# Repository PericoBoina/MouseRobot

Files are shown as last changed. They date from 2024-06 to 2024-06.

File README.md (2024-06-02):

# Robot-Laberinto

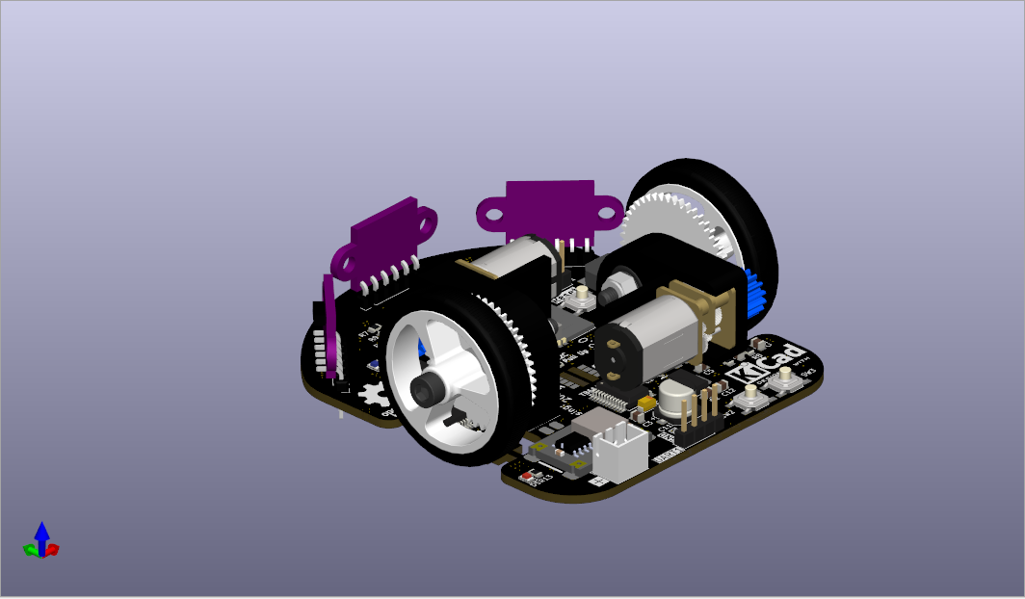
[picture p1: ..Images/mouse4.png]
Mouse3
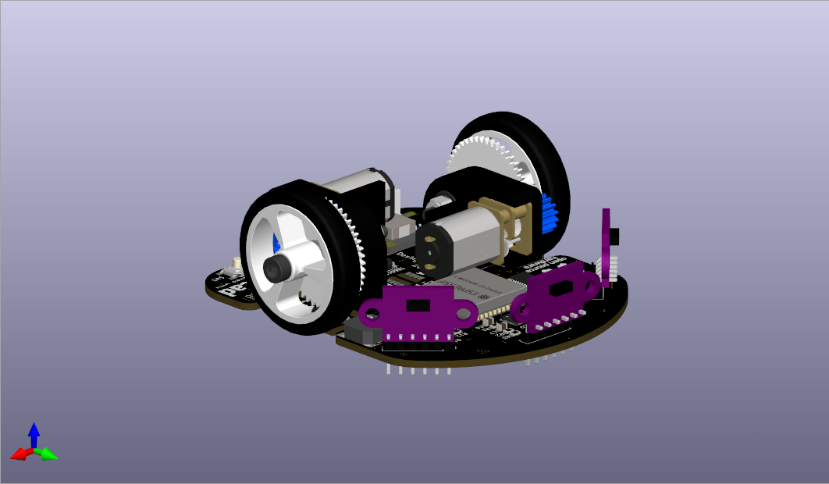
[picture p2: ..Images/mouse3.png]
Mouse4


## 👽 Hardware 👽

| | | 
|---|---  |
| Motors | N20 800RPM 6V |
| MCU | ESP32 Wroom 32U |
| Giroscope  | MPU6050 |
| Encoders | AS5145B |
| Sensors | VL53L0X |
| Wheel Gear | 48T 0.5MM(module)  |
| Motor Gear | 15T 0.5MM(module)  |

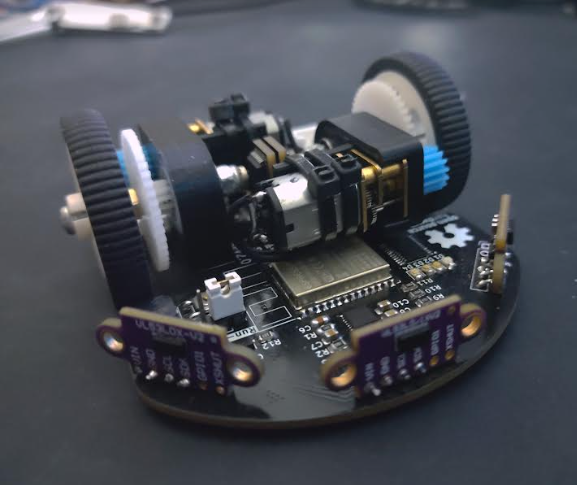
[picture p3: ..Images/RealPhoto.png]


---

Desing: Perico_197⚡

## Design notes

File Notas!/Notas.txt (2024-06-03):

Programacion:
---- Odometria:
        ***PROBLEMA RESETEO CONSTANTE AL INCLUIR LA LIBRERIA*** ☠️

---- Motion:
        *Funcion para giros -> meter funcion otro codigo nose donde esta ☠️
        *Motion -> Straight:
                * Funcion para avanzar completamente recto mediante gyro -> 🙈🙈
                * Avanzar distancia (mm) deseada -> 🙈😵‍💫

---- Sensor library:
         * algoritmo lectura paredes  -> 👍👍
         * mpu6050 hacer que aranque a 0 ->  😵‍💫
         * meter valor gyro z + inicio + ofset en libreria sensors -> 👍👍
        
---- Importante sino no se puede avanzar!!
        *averiguar que valor dan los getCount de los encoder en 1 milimetro --> 😡

-- Robot (Hardware): 
         ---- encoder ----> 👍👍      ---- buttons   ----> 👍👍     ----  leds   ----> 👍👍   
         ---- vl53l0x ----> 👍👍      ---- tb6612fng ----> 👍👍    
         ---- MPU6050 ----> 👍👍      ---- tca9548   ----> 👍👍

Emojis programing level:

         ---- 😁😁😁😁😁 ----  -> easy
         ---- 🙈🙈🙈🙈🙈 ----  -> normal
         ---- 😵‍💫😵‍💫😵‍💫😵‍💫😵‍💫 ----  -> difficult
         ---- 😡😡😡😡😡 ----  -> xtreme difficult      
         ---- ☠️☠️☠️☠️☠️ ----  -> kill me

Comandos GIT:
git init 
git commit -am "First commit"

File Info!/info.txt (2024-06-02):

Enlaces :
- https://en.wikipedia.org/wiki/Differential_wheeled_robot // Documentacion

- https://drive.google.com/file/d/1HS-5pF-UFEItbylbGvAekCrKYQvqzdeI/view //Ejemplo Arduino Odometria

- https://github.com/alfa934/wheel-odometry-arduino/blob/main/krtmi_odometry.ino // Ejemplo ArDuino Odometria
  
- http://micromouseusa.com/?page_id=1342

- https://github.com/idt12312/MIZUHO.git --> repo japo! 😁😁//

https://youtube.com/shorts/J72pE9Ghk50?si=G8V3c-wjg9_S6Kjb

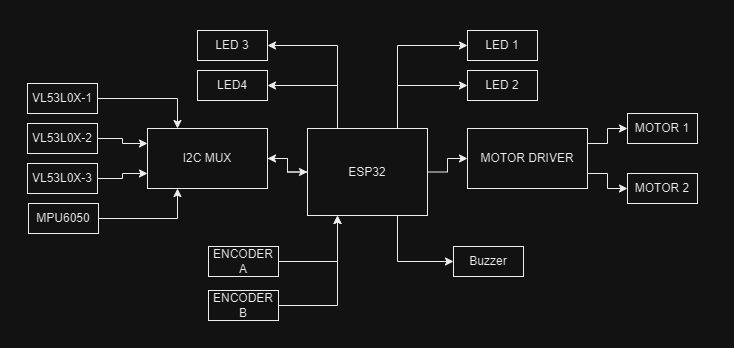
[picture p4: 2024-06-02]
..Schematic/schematic_1.png

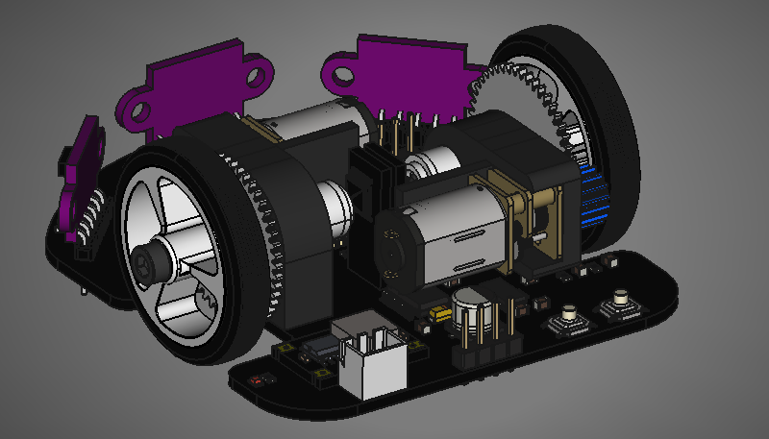
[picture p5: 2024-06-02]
..Images/mouse2.png

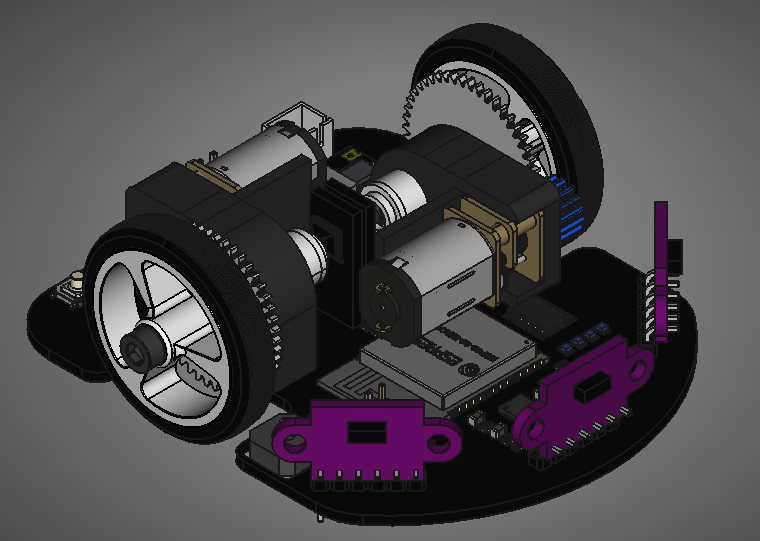
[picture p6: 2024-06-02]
..Images/mouse1.png

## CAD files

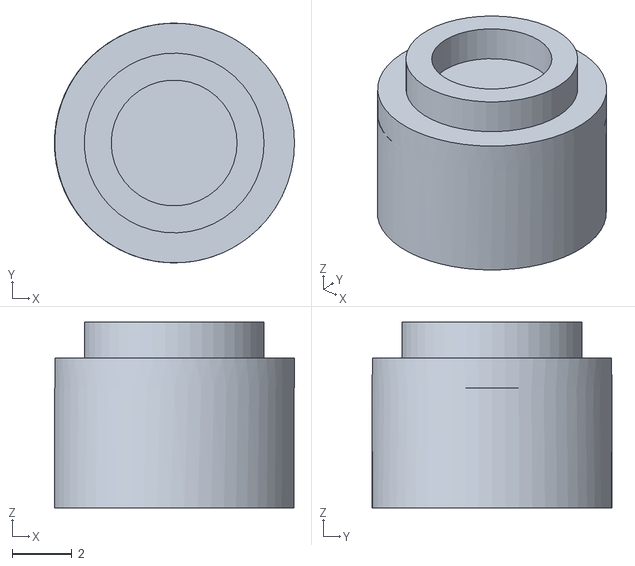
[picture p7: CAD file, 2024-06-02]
..FreeCAD desing/Mouse-Pieza para iman.stl
8.01 x 8.00 x 6.20

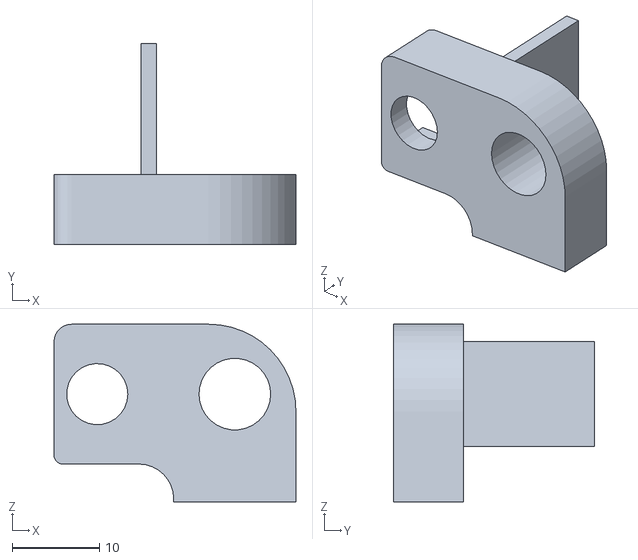
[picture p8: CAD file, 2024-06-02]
..FreeCAD desing/Mouse-Reductora.stl
27.7 x 23.0 x 20.3

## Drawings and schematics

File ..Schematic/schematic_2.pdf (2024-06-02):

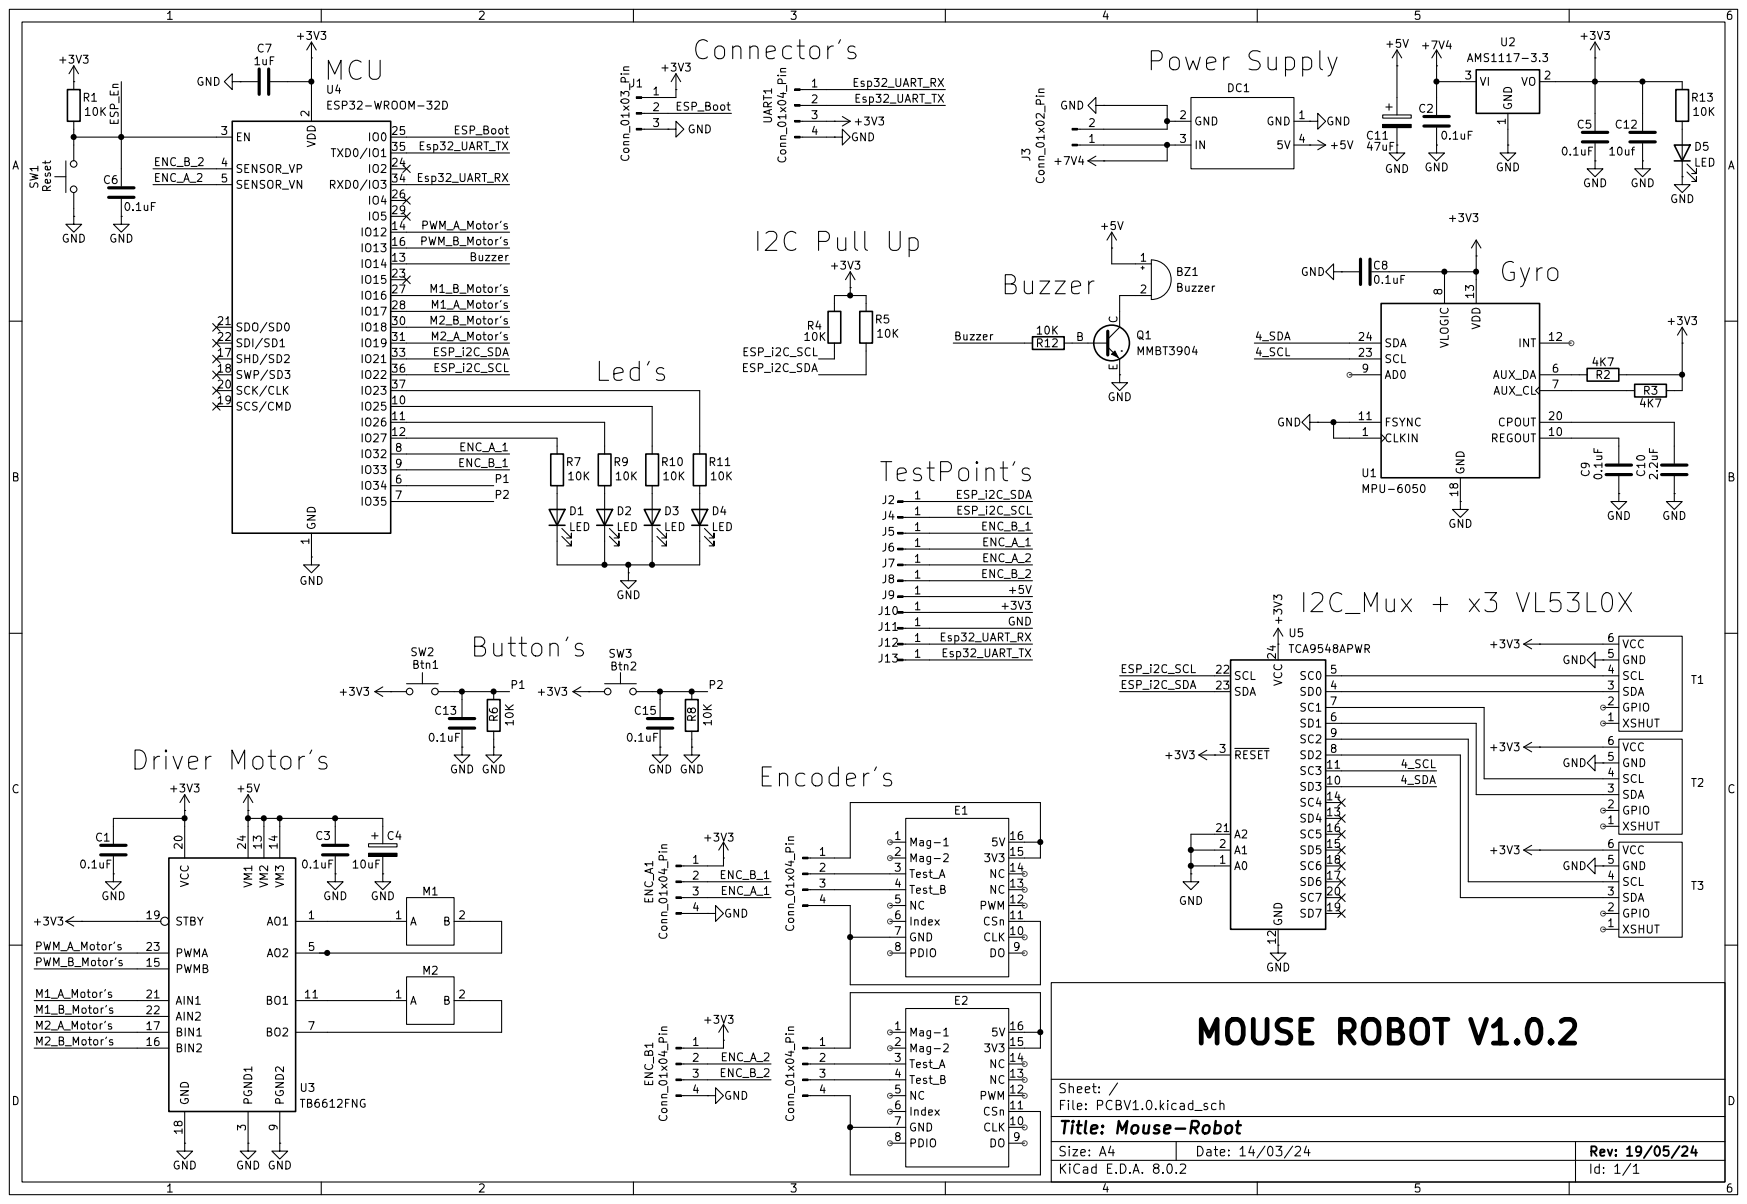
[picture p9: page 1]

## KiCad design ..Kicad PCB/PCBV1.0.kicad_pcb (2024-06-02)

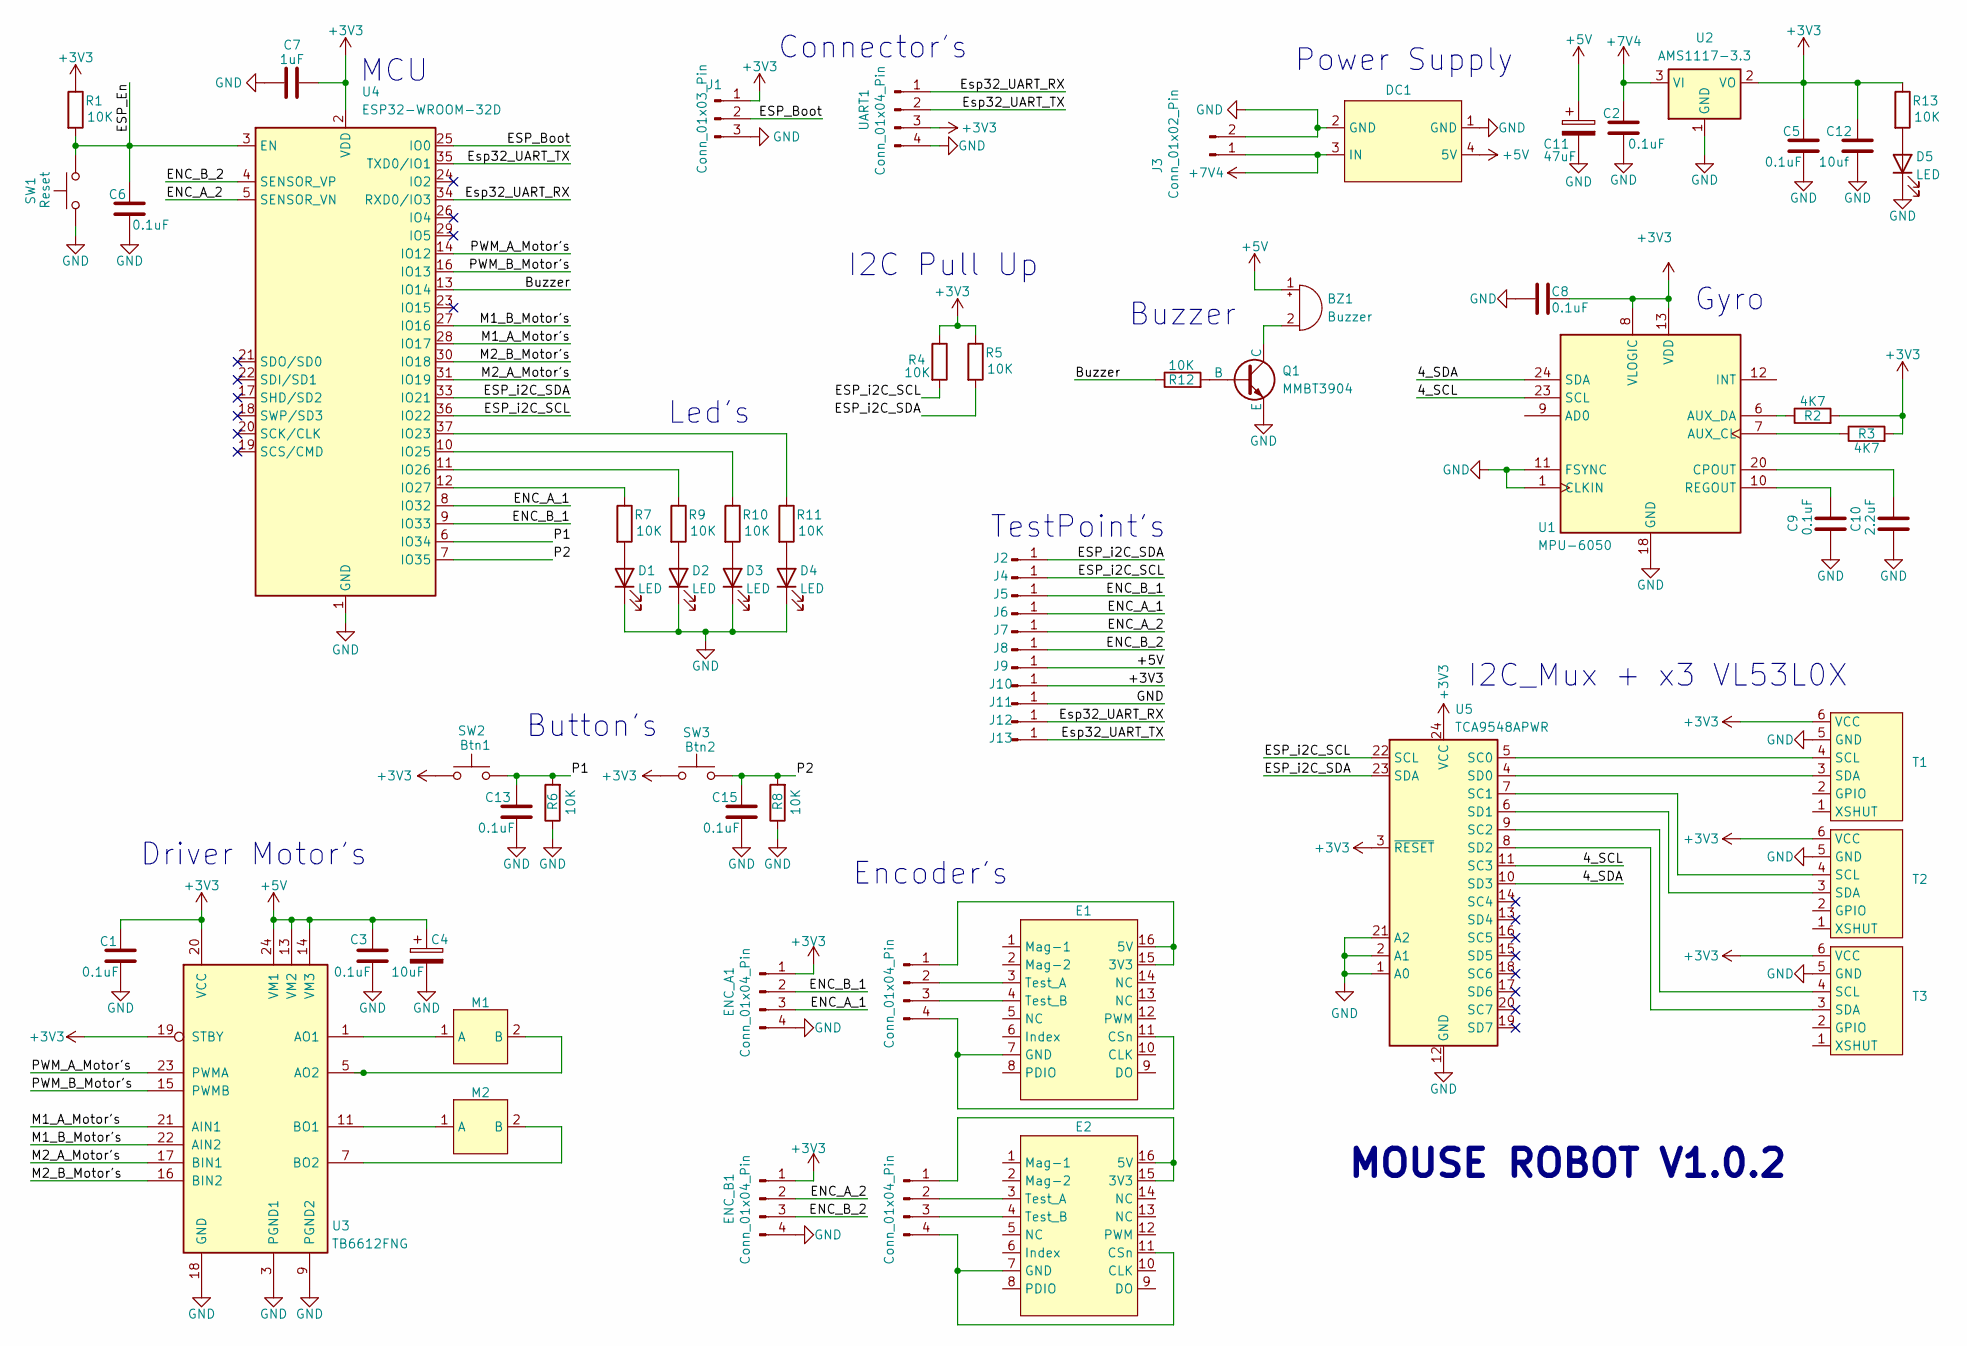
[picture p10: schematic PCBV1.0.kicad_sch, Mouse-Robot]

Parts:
BZ1: Buzzer; MLT2575
C1, C2, C3, C5, C6, C8, C9, C13, C15: 0.1uF; C_0805_2012Metric
C4: 10uF; CP_EIA-3216-18_Kemet-A
C7: 1uF; C_0805_2012Metric
C10: 2.2uF; C_0805_2012Metric
C11: 47uF; CP_Elec_6.3x5.4
C12: 10uf; C_0805_2012Metric
D1, D2, D3, D4, D5: LED; LED_0805_2012Metric
DC1: 5v MODULE
E1, E2: SSOP-16_5.3x6.2mm_P0.65mm
ENC_A1: Conn_01x04_Pin; PinHeader_1x04_P2.54mm_Vertical
ENC_B1, ENC_B2, ENC_B3: Conn_01x04_Pin; PinHeader_1x04_P2.54mm_Vertical
J1: Conn_01x03_Pin; PinHeader_1x03_P2.54mm_Vertical
J2, J4, J5, J6, J7, J8, J9, J10, J11, J12, J13: Conn_01x01_Pin; TestPoint_Pad_D1.0mm
J3: Conn_01x02_Pin; JST_XH_B2B-XH-AM_1x02_P2.50mm_Vertical
M1, M2: M
Q1: MMBT3904; SOT-23
R1, R4, R5, R6, R7, R8, R9, R10, R11, R12, R13: 10K; R_0805_2012Metric
R2, R3: 4K7; R_0805_2012Metric
SW1: Reset; SW_SPST_SKQG_WithStem
SW2: Btn1; SW_SPST_SKQG_WithStem
SW3: Btn2; SW_SPST_SKQG_WithStem
T1, T2, T3: PinHeader_1x06_P2.54mm_Vertical
U1: MPU-6050; InvenSense_QFN-24_4x4mm_P0.5mm
U2: AMS1117-3.3; SOT-223-3_TabPin2
U3: TB6612FNG; SSOP-24_5.3x8.2mm_P0.65mm
U4: ESP32-WROOM-32D
U5: TCA9548APWR; TSSOP-24_4.4x7.8mm_P0.65mm
UART1: Conn_01x04_Pin; PinHeader_1x04_P2.54mm_Vertical

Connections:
+3V3: C1.1, C5.1, C7.1, C8.2, C12.1, ENC_A1.1, ENC_B1.1, J1.1, J10.1, R1.1, R2.2, R3.2, R4.1, R5.1, R13.1, SW2.1, SW3.1, T1.6 (VCC), T2.6 (VCC), T3.6 (VCC), U1.8 (VLOGIC), U1.13 (VDD), U2.2 (VO), U3.19 (STBY), U3.20 (VCC), U4.2 (VDD), U5.3 (~RESET), U5.24 (VCC), UART1.3
+5V: BZ1.1 (+), C3.1, C4.1, C11.1, DC1.4 (5V), J9.1, U3.13 (VM2), U3.14 (VM3), U3.24 (VM1)
+7V4: C2.1, DC1.3 (IN), J3.1, U2.3 (VI)
/4_SCL: U1.23 (SCL), U5.11 (SC3)
/4_SDA: U1.24 (SDA), U5.10 (SD3)
/Buzzer: R12.1, U4.13 (IO14)
/ENC_A_1: ENC_A1.3, J6.1, U4.8 (IO32)
/ENC_A_2: ENC_B1.2, J7.1, U4.5 (SENSOR_VN)
/ENC_B_1: ENC_A1.2, J5.1, U4.9 (IO33)
/ENC_B_2: ENC_B1.3, J8.1, U4.4 (SENSOR_VP)
/ESP_Boot: J1.2, U4.25 (IO0)
/ESP_En: C6.1, R1.2, SW1.2, U4.3 (EN)
/ESP_i2C_SCL: J4.1, R4.2, U4.36 (IO22), U5.22 (SCL)
/ESP_i2C_SDA: J2.1, R5.2, U4.33 (IO21), U5.23 (SDA)
/Esp32_UART_RX: J12.1, U4.34 (RXD0/IO3), UART1.1
/Esp32_UART_TX: J13.1, U4.35 (TXD0/IO1), UART1.2
/M1_A_Motor's: U3.21 (AIN1), U4.28 (IO17)
/M1_B_Motor's: U3.22 (AIN2), U4.27 (IO16)
/M2_A_Motor's: U3.17 (BIN1), U4.31 (IO19)
/M2_B_Motor's: U3.16 (BIN2), U4.30 (IO18)
/P1: C13.1, R6.2, SW2.2, U4.6 (IO34)
/P2: C15.1, R8.2, SW3.2, U4.7 (IO35)
/PWM_A_Motor's: U3.23 (PWMA), U4.14 (IO12)
/PWM_B_Motor's: U3.15 (PWMB), U4.16 (IO13)
GND: C1.2, C2.2, C3.2, C4.2, C5.2, C6.2, C7.2, C8.1, C9.2, C10.2, C11.2, C12.2, C13.2, C15.2, D1.1 (K), D2.1 (K), D3.1 (K), D4.1 (K), D5.1 (K), DC1.1 (GND), DC1.2 (GND), ENC_A1.4, ENC_B1.4, J1.3, J3.2, J11.1, Q1.3 (E), R6.1, R8.1, SW1.1, T1.5 (GND), T2.5 (GND), T3.5 (GND), U1.1 (CLKIN), U1.11 (FSYNC), U1.18 (GND), U2.1 (GND), U3.3 (PGND1), U3.4 (PGND1), U3.9 (PGND2), U3.10 (PGND2), U3.18 (GND), U4.1 (GND), U4.15 (GND), U4.38 (GND), U4.39 (GND), U5.1 (A0), U5.2 (A1), U5.12 (GND), U5.21 (A2), UART1.4
unnamed: BZ1.2 (-), Q1.1 (C)
unnamed: D1.2 (A), R7.2
unnamed: D2.2 (A), R9.2
unnamed: D3.2 (A), R10.2
unnamed: D4.2 (A), R11.2
unnamed: D5.2 (A), R13.2
unnamed: E1.15 (3V3), E1.16 (5V), ENC_B2.1
unnamed: E1.7 (GND), E1.11 (CSn), ENC_B2.4
unnamed: E1.3 (Test_A), ENC_B2.2
unnamed: E1.4 (Test_B), ENC_B2.3
unnamed: E2.15 (3V3), E2.16 (5V), ENC_B3.1
unnamed: E2.7 (GND), E2.11 (CSn), ENC_B3.4
unnamed: E2.3 (Test_A), ENC_B3.2
unnamed: E2.4 (Test_B), ENC_B3.3
unnamed: M1.1 (A), U3.1 (AO1), U3.2 (AO1)
unnamed: M1.2 (B), U3.5 (AO2), U3.6 (AO2)
unnamed: M2.1 (A), U3.11 (BO1), U3.12 (BO1)
unnamed: M2.2 (B), U3.7 (BO2), U3.8 (BO2)
unnamed: Q1.2 (B), R12.2
unnamed: T1.4 (SCL), U5.5 (SC0)
unnamed: T1.3 (SDA), U5.4 (SD0)
unnamed: T2.4 (SCL), U5.7 (SC1)
unnamed: T2.3 (SDA), U5.6 (SD1)
unnamed: T3.4 (SCL), U5.9 (SC2)
unnamed: T3.3 (SDA), U5.8 (SD2)
unnamed: R3.1, U1.7 (AUX_CL)
unnamed: R2.1, U1.6 (AUX_DA)
unnamed: C10.1, U1.20 (CPOUT)
unnamed: C9.1, U1.10 (REGOUT)
unnamed: R11.1, U4.37 (IO23)
unnamed: R10.1, U4.10 (IO25)
unnamed: R9.1, U4.11 (IO26)
unnamed: R7.1, U4.12 (IO27)

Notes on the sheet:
Power Supply
TestPoint's
MCU
Encoder's
Buzzer
Driver Motor's
Button's
Led's
Connector's
Gyro
I2C_Mux + x3 VL53L0X
MOUSE ROBOT V1.0.2
I2C Pull Up

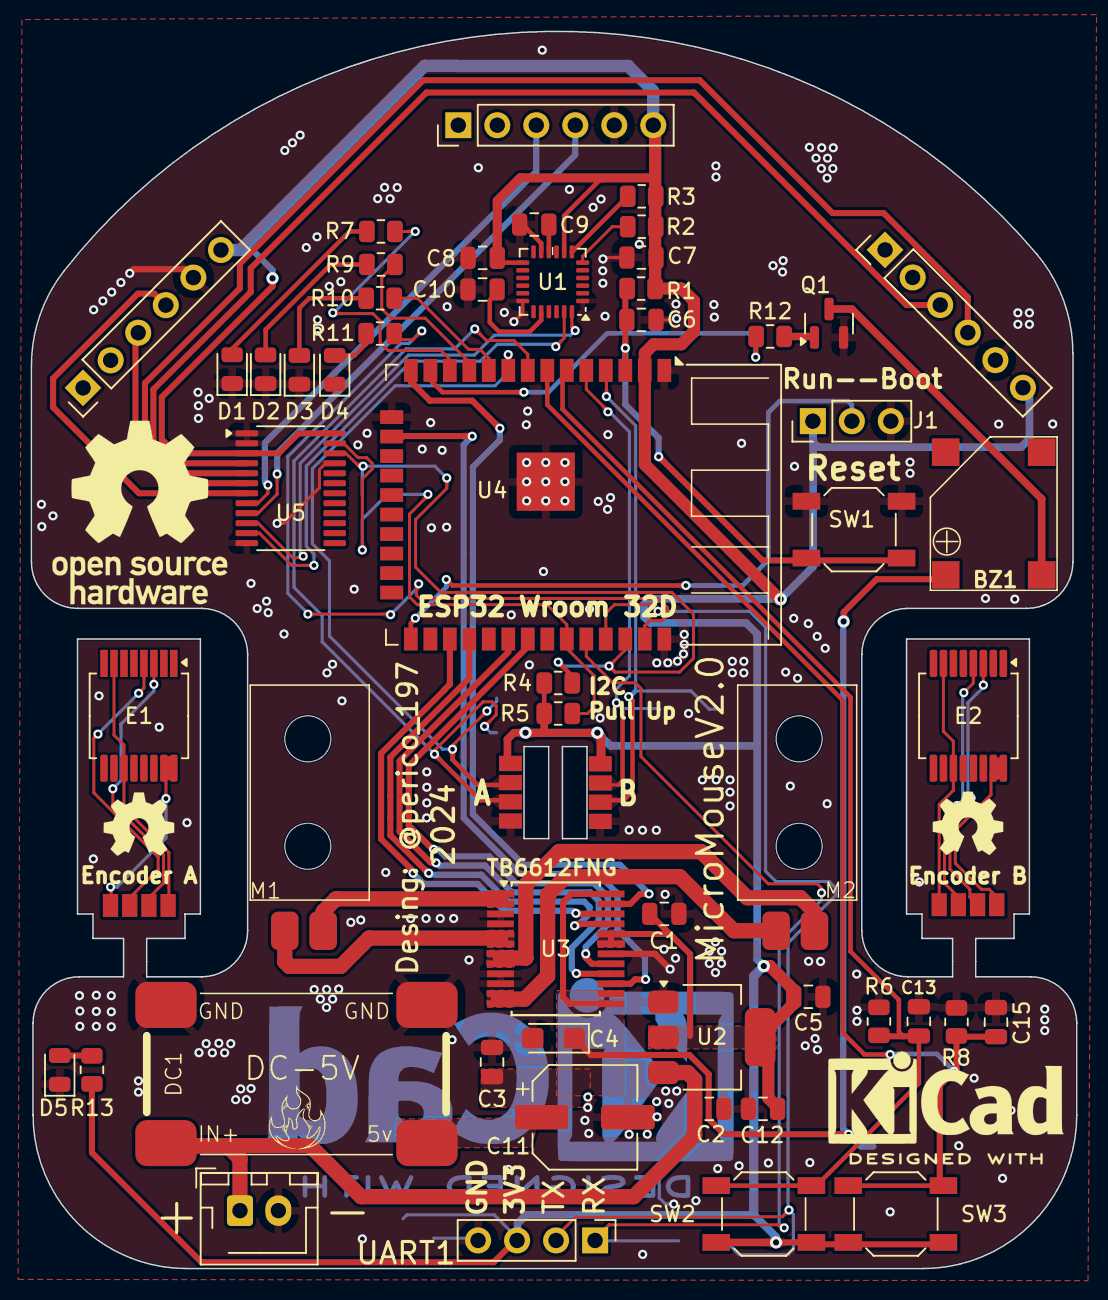
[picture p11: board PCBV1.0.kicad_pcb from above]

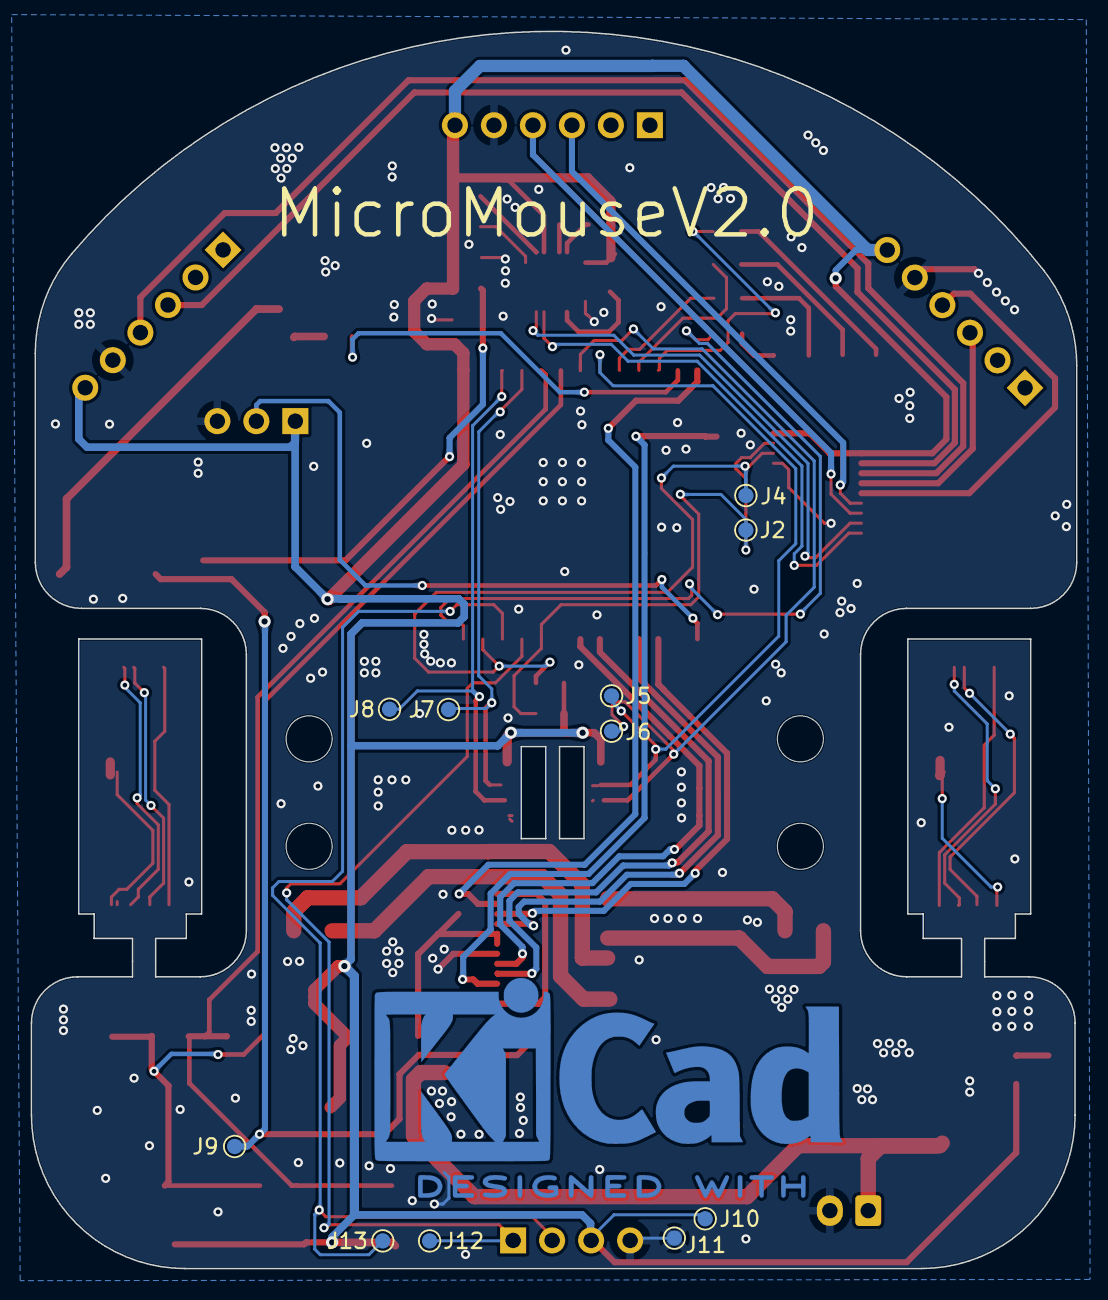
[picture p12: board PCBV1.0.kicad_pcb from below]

Board: 2 copper layers, 68.1 x 80.6 mm, 68 parts (11 on the bottom side), 58 nets.

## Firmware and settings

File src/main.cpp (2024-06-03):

#include <Arduino.h>
#include <Add/Led.h>
#include <Add/Buttons.h>
#include <Add/I2CMux.h>
#include <Add/DataBT.h>
#include <Add/MadgwickAHRS.h>
#include <Motion/MotorController.h>
#include <Motion/Motion.h>
#include <Sensors/Sensor.h>
#include <Sensors/Encoders.h>
#include <Sensors/MPU6050_light.h>
#include <BluetoothSerial.h>

I2CMux mux(0x70);
Sensor sensor;
Encoders enc;
Led led;
MotorController motor;
Buttons button;
BluetoothSerial SerialBT;
DataBT dataBT;
MPU6050 mpu(Wire);
Motion move;



void setup()
{
  Serial.begin(115200);
  Wire.begin(21, 22);
  SerialBT.begin("MouseRobot");
  sensor.init();
  button.init();
  motor.init();
  enc.init();
  led.init();
  led.show();
}

void loop()
{
  move.Straight();
}

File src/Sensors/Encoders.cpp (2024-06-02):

#include "Sensors/Encoders.h"

Encoders *Encoders::_encoderInstance = nullptr;

Encoders::Encoders()
{
  _encoderInstance = this;
}

void Encoders::init()
{
  pinMode(pinA1, INPUT_PULLUP);
  pinMode(pinB1, INPUT_PULLUP);
  pinMode(pinA2, INPUT_PULLUP);
  pinMode(pinB2, INPUT_PULLUP);
  attachInterrupt(digitalPinToInterrupt(pinA1), updateEncoder1, CHANGE);
  attachInterrupt(digitalPinToInterrupt(pinB1), updateEncoder1, CHANGE);
  attachInterrupt(digitalPinToInterrupt(pinA2), updateEncoder2, CHANGE);
  attachInterrupt(digitalPinToInterrupt(pinB2), updateEncoder2, CHANGE);
}

void IRAM_ATTR Encoders::updateEncoder1()
{
  int MSB1 = digitalRead(_encoderInstance->pinA1);
  int LSB1 = digitalRead(_encoderInstance->pinB1);
  int encoded1 = (MSB1 << 1) | LSB1;
  int sum1 = (_encoderInstance->_lastEncoded1 << 2) | encoded1;
  if ((sum1 == 0b1101) || (sum1 == 0b0100) || (sum1 == 0b0010) || (sum1 == 0b1011))
  {
    _encoderInstance->_encoderPos1++;
  }
  else if ((sum1 == 0b1110) || (sum1 == 0b0111) || (sum1 == 0b0001) || (sum1 == 0b1000))
  {
    _encoderInstance->_encoderPos1--;
  }
  _encoderInstance->_lastEncoded1 = encoded1;
}

void IRAM_ATTR Encoders::updateEncoder2()
{
  int MSB2 = digitalRead(_encoderInstance->pinA2);
  int LSB2 = digitalRead(_encoderInstance->pinB2);
  int encoded2 = (MSB2 << 1) | LSB2;
  int sum2 = (_encoderInstance->_lastEncoded2 << 2) | encoded2;
  if ((sum2 == 0b1101) || (sum2 == 0b0100) || (sum2 == 0b0010) || (sum2 == 0b1011))
  {
    _encoderInstance->_encoderPos2++;
  }
  else if ((sum2 == 0b1110) || (sum2 == 0b0111) || (sum2 == 0b0001) || (sum2 == 0b1000))
  {
    _encoderInstance->_encoderPos2--;
  }
  _encoderInstance->_lastEncoded2 = encoded2;
}

int Encoders::getCount(int encoderNum)
{
  if (encoderNum == 1)
  {
    return _encoderPos1;
  }
  else if (encoderNum == 2)
  {
    return _encoderPos2;
  }
  else
  {
    return 0;
  }
}

void Encoders::reset(int encoderNum)
{
  if (encoderNum == 1)
  {
    _encoderPos1 = 0;
  }
  if (encoderNum == 2)
  {
    _encoderPos2 = 0;
  }
}

float Encoders::angular_L()
{
  lastCountL = countL;
  countL = getCount(1);
  float dtL = static_cast<float>(lastCountL - countL);
  dtLBuffer[dtLIndex] = dtL;
  float sumL = 0.0;
  for (int i = 0; i < numSamples; ++i)
  {
    sumL += dtLBuffer[i];
  }
  dtLIndex = (dtLIndex + 1) % numSamples;
  float ang_L = (sumL / numSamples / encoderStepsPerRev) * (2.0 * pi);
  float omega_L = ang_L / dt;
  return omega_L;
}
float Encoders::angular_R()
{
  lastCountR = countR;
  countR = getCount(2);
  float dtR = static_cast<float>(lastCountR - countR);
  dtRBuffer[dtRIndex] = dtR;
  float sumR = 0.0;
  for (int i = 0; i < numSamples; ++i)
  {
    sumR += dtRBuffer[i];
  }
  dtRIndex = (dtRIndex + 1) % numSamples;
  float ang_R = (sumR / numSamples / encoderStepsPerRev) * (2.0 * pi);
  float omega_R = ang_R / dt;
  return omega_R;
}

float Encoders::lineal_L()
{
  float lineal_L = angular_L() * wheelRadiusMM;
  return lineal_L;
}

float Encoders::lineal_R()
{
  float lineal_R = angular_R() * wheelRadiusMM;
  return lineal_R;
}

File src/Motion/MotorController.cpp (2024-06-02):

#include"Motion/MotorController.h"

MotorController::MotorController()
{
}

void MotorController::init()
{
    pinMode(motorA1, OUTPUT);
    pinMode(motorA2, OUTPUT);
    pinMode(motorB1, OUTPUT);
    pinMode(motorB2, OUTPUT);
    ledcSetup(ledChannel0, 10000, 8); // 10Khz PWMA
    ledcSetup(ledChannel1, 10000, 8); // 10Khz PWMB
    ledcAttachPin(motorAPwm, ledChannel0);
    ledcAttachPin(motorBPwm, ledChannel1);
}

void MotorController::M1_FWD(int Speed)
{
    digitalWrite(motorA1, LOW);
    digitalWrite(motorA2, HIGH);
    ledcWrite(ledChannel0, Speed);
}

void MotorController::M2_FWD(int Speed)
{
    digitalWrite(motorB1, LOW);
    digitalWrite(motorB2, HIGH);
    ledcWrite(ledChannel1, Speed);
}

void MotorController::M1_BKC(int Speed)
{
    digitalWrite(motorA1, HIGH);
    digitalWrite(motorA2, LOW);
    ledcWrite(ledChannel0, Speed);
}

void MotorController::M2_BKC(int Speed)
{
    digitalWrite(motorB1, HIGH);
    digitalWrite(motorB2, LOW);
    ledcWrite(ledChannel1, Speed);
}

void MotorController::M1_Stop()
{
    digitalWrite(motorA1, LOW);
    digitalWrite(motorA2, LOW);
    ledcWrite(ledChannel0, 0);
}

void MotorController::M2_Stop()
{
    digitalWrite(motorB1, LOW);
    digitalWrite(motorB2, LOW);
    ledcWrite(ledChannel1, 0);
}

void MotorController::all_Stop()
{
    M1_Stop();
    M2_Stop();
}
